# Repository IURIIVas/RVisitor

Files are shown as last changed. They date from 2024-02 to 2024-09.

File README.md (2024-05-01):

# RVisitor

Automated robot motion control module

## Description

The module allows to assign the control functions of a wheeled robot to a separate functional unit, reducing the requirements for robot software.   

### Application area
The module provides control of DC motors taking into account information from connected sensors. The module can be used for:
* studying the basic robotic algorithms for controlling the movement of wheeled robots
* research and development of robotic platforms

### Features

* setting and maintaining speed and direction of movement
* identification of obstacles and lack of surface
* wheel odometry
* high current level detection
* configuration save

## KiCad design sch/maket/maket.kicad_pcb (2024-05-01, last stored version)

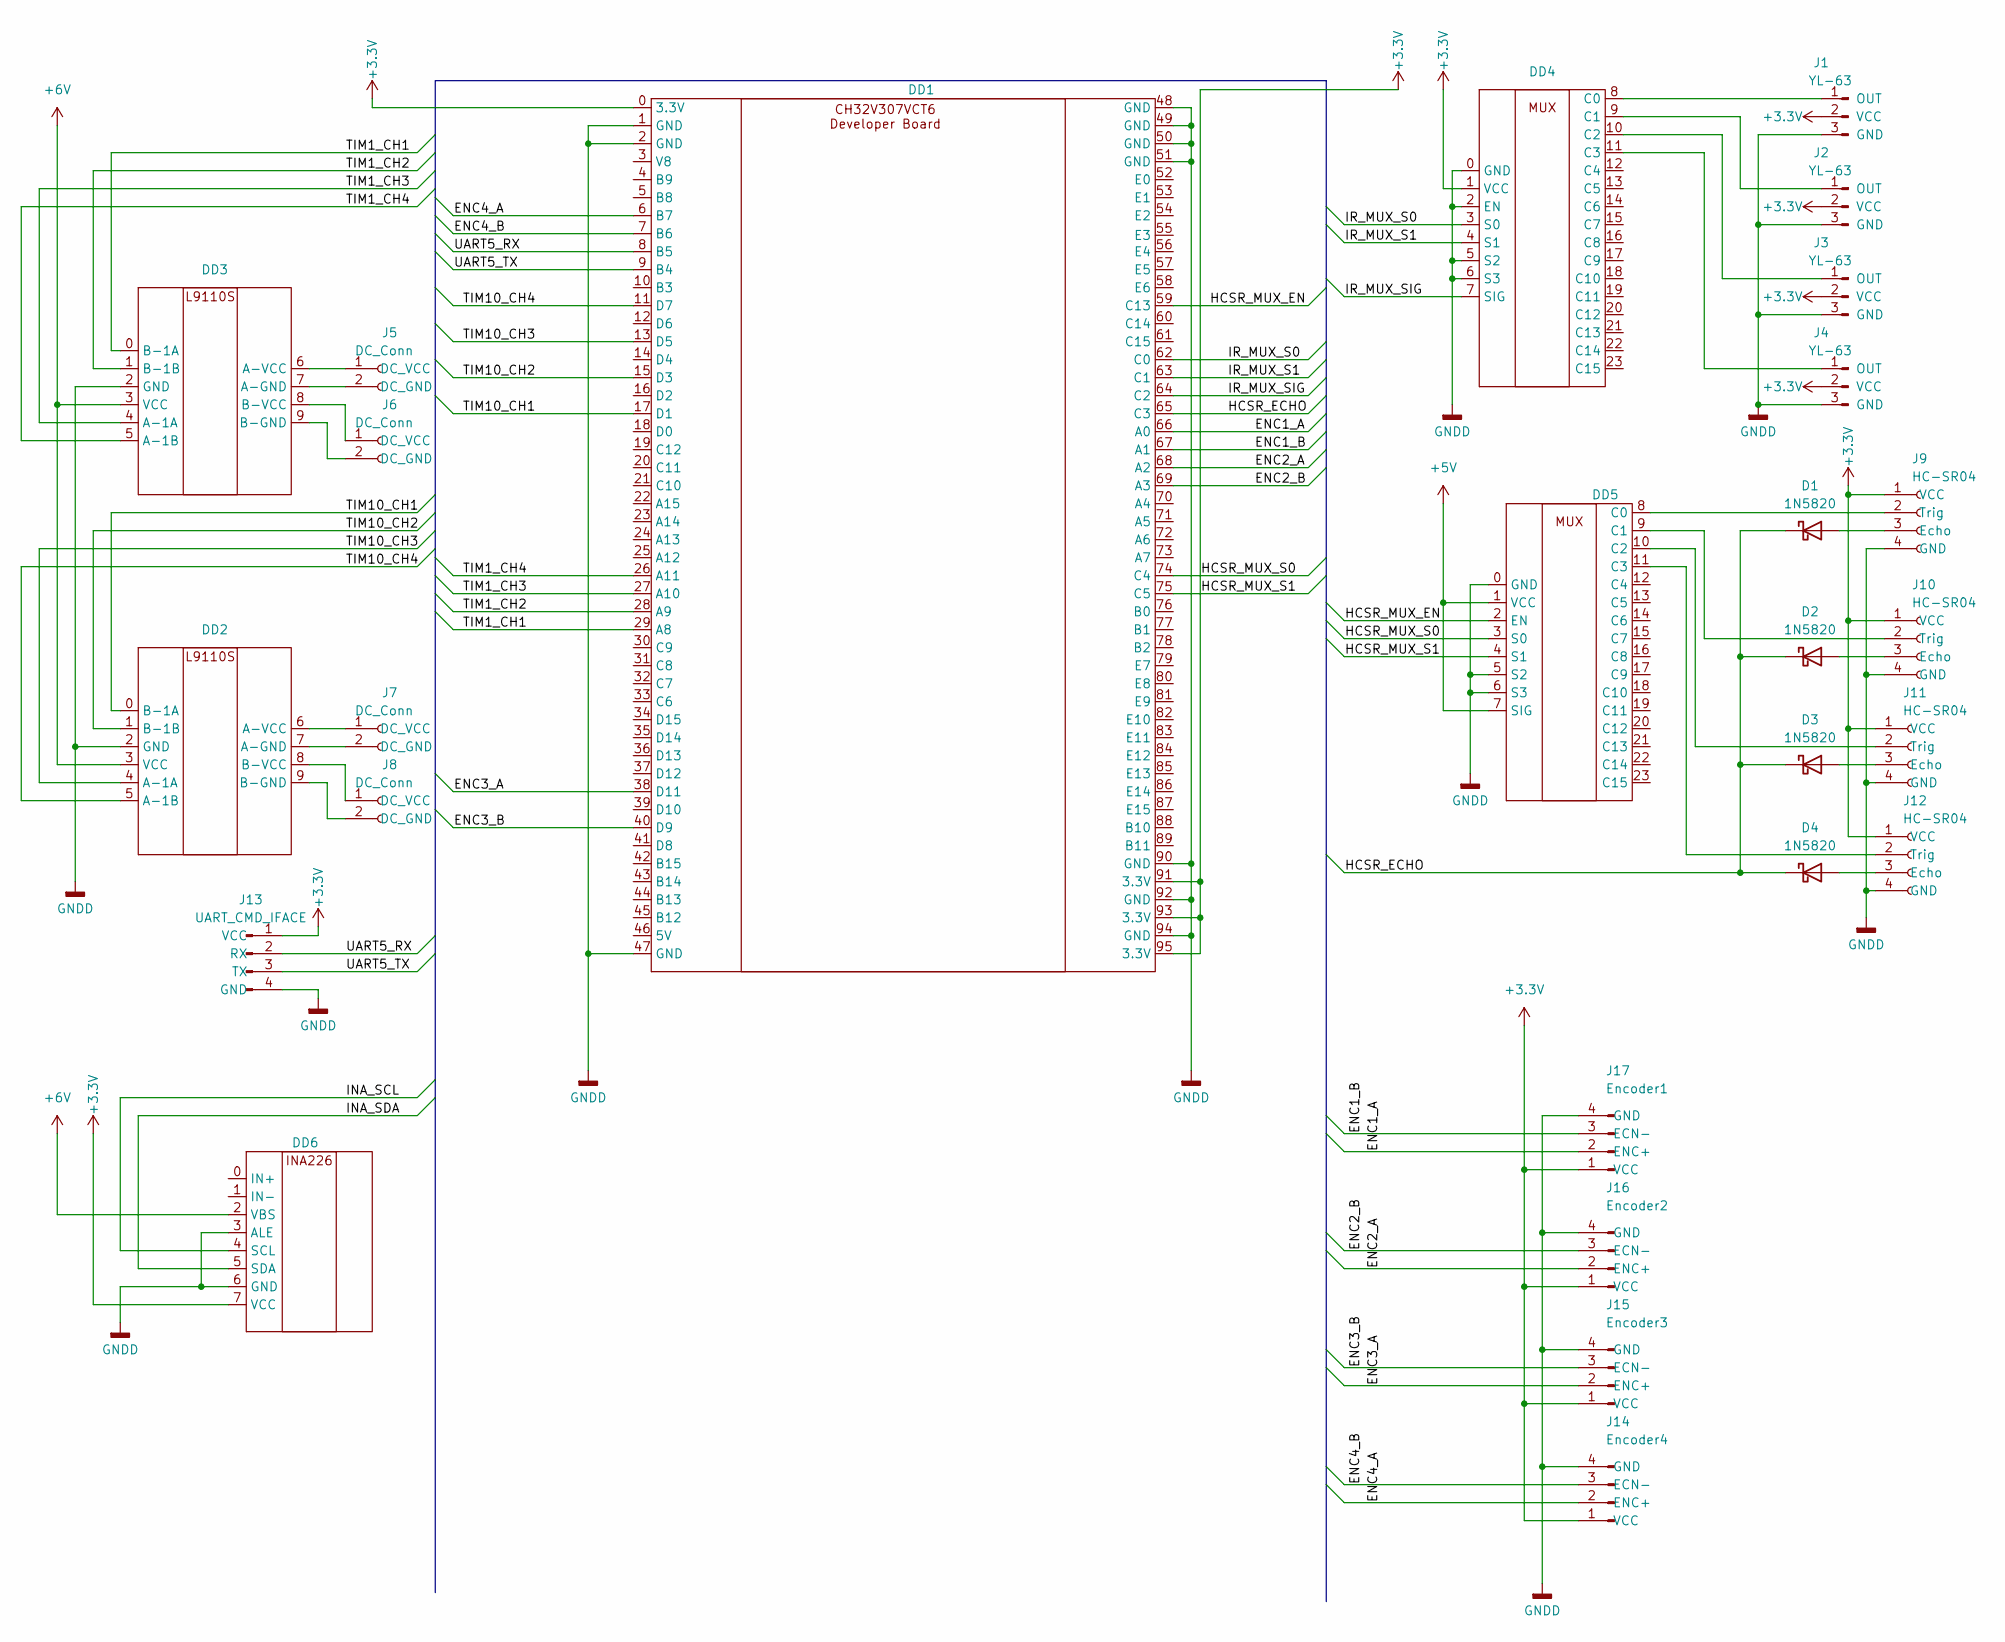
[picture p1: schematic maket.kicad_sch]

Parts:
D1, D2, D3, D4: 1N5820; D_DO-201AD_P15.24mm_Horizontal
DD1: CH32V307VCT6 dev board
DD2, DD3: L9110S
DD4, DD5: CD74HC4067_GOOD
DD6: INA226
J1, J2, J3, J4: YL-63; PinHeader_1x03_P2.54mm_Vertical
J5, J6, J7, J8: DC_Conn; JST_PH_S2B-PH-K_1x02_P2.00mm_Horizontal
J9, J10, J11, J12: HC-SR04; PinSocket_1x04_P2.54mm_Vertical
J13: UART_CMD_IFACE; PinSocket_1x04_P2.54mm_Vertical
J14: Encoder4; JST_PH_S4B-PH-K_1x04_P2.00mm_Horizontal
J15: Encoder3; JST_PH_S4B-PH-K_1x04_P2.00mm_Horizontal
J16: Encoder2; JST_PH_S4B-PH-K_1x04_P2.00mm_Horizontal
J17: Encoder1; JST_PH_S4B-PH-K_1x04_P2.00mm_Horizontal

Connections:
+3.3V: DD1.0 (3.3V), DD1.74 (C4), DD1.75 (C5), DD1.91 (3.3V), DD1.93 (3.3V), DD1.95 (3.3V), DD4.1 (VCC), DD5.3 (S0), DD5.4 (S1), DD6.7 (VCC), J1.2 (VCC), J2.2 (VCC), J3.2 (VCC), J4.2 (VCC), J9.1 (VCC), J10.1 (VCC), J11.1 (VCC), J12.1 (VCC), J13.1 (VCC), J14.1 (VCC), J15.1 (VCC), J16.1 (VCC), J17.1 (VCC)
+5V: DD5.1 (VCC), DD5.7 (SIG)
+6V: DD2.3 (VCC), DD3.3 (VCC), DD6.2 (VBS)
/ENC1_A: DD1.66 (A0), J17.2 (ENC+)
/ENC1_B: DD1.67 (A1), J17.3 (ECN-)
/ENC2_A: DD1.68 (A2), J16.2 (ENC+)
/ENC2_B: DD1.69 (A3), J16.3 (ECN-)
/ENC3_A: DD1.38 (D11), J15.2 (ENC+)
/ENC3_B: DD1.40 (D9), J15.3 (ECN-)
/ENC4_A: DD1.6 (B7), J14.2 (ENC+)
/ENC4_B: DD1.7 (B6), J14.3 (ECN-)
/HCSR_ECHO: D1.1 (K), D2.1 (K), D3.1 (K), D4.1 (K), DD1.65 (C3)
/HCSR_MUX_EN: DD1.59 (C13), DD5.2 (EN)
/INA_SCL: DD6.4 (SCL)
/INA_SDA: DD6.5 (SDA)
/IR_MUX_S0: DD1.62 (C0), DD4.3 (S0)
/IR_MUX_S1: DD1.63 (C1), DD4.4 (S1)
/IR_MUX_SIG: DD1.64 (C2), DD4.7 (SIG)
/TIM1_CH1: DD1.29 (A8), DD3.0 (B-1A)
/TIM1_CH2: DD1.28 (A9), DD3.1 (B-1B)
/TIM1_CH3: DD1.27 (A10), DD3.4 (A-1A)
/TIM1_CH4: DD1.26 (A11), DD3.5 (A-1B)
/TIM10_CH1: DD1.17 (D1), DD2.0 (B-1A)
/TIM10_CH2: DD1.15 (D3), DD2.1 (B-1B)
/TIM10_CH3: DD1.13 (D5), DD2.4 (A-1A)
/TIM10_CH4: DD1.11 (D7), DD2.5 (A-1B)
/UART5_RX: DD1.8 (B5), J13.2 (RX)
/UART5_TX: DD1.9 (B4), J13.3 (TX)
GNDD: DD1.1 (GND), DD1.2 (GND), DD1.47 (GND), DD1.48 (GND), DD1.49 (GND), DD1.50 (GND), DD1.51 (GND), DD1.90 (GND), DD1.92 (GND), DD1.94 (GND), DD2.2 (GND), DD3.2 (GND), DD4.0 (GND), DD4.2 (EN), DD4.5 (S2), DD4.6 (S3), DD5.0 (GND), DD5.5 (S2), DD5.6 (S3), DD6.3 (ALE), DD6.6 (GND), J1.3 (GND), J2.3 (GND), J3.3 (GND), J4.3 (GND), J9.4 (GND), J10.4 (GND), J11.4 (GND), J12.4 (GND), J13.4 (GND), J14.4 (GND), J15.4 (GND), J16.4 (GND), J17.4 (GND)
unnamed: D1.2 (A), J9.3 (Echo)
unnamed: D2.2 (A), J10.3 (Echo)
unnamed: D3.2 (A), J11.3 (Echo)
unnamed: D4.2 (A), J12.3 (Echo)
unnamed: DD2.7 (A-GND), J7.2 (DC_GND)
unnamed: DD2.6 (A-VCC), J7.1 (DC_VCC)
unnamed: DD2.9 (B-GND), J8.2 (DC_GND)
unnamed: DD2.8 (B-VCC), J8.1 (DC_VCC)
unnamed: DD3.7 (A-GND), J5.2 (DC_GND)
unnamed: DD3.6 (A-VCC), J5.1 (DC_VCC)
unnamed: DD3.9 (B-GND), J6.2 (DC_GND)
unnamed: DD3.8 (B-VCC), J6.1 (DC_VCC)
unnamed: DD4.8 (C0), J1.1 (OUT)
unnamed: DD4.9 (C1), J2.1 (OUT)
unnamed: DD4.10 (C2), J3.1 (OUT)
unnamed: DD4.11 (C3), J4.1 (OUT)
unnamed: DD5.8 (C0), J9.2 (Trig)
unnamed: DD5.9 (C1), J10.2 (Trig)
unnamed: DD5.10 (C2), J11.2 (Trig)
unnamed: DD5.11 (C3), J12.2 (Trig)

Board: 2 copper layers, 27 parts (0 on the bottom side), 47 nets, no tracks yet.

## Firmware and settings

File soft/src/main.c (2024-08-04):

/// \file main.c
/// \brief Main file.
/// \author 1jura.vas@gmail.com
///
/// \details
///

//----------------------------------------------------- Includes -------------------------------------------------------

#include "global_inc.h"
#include "misc.h"
#include "system_ch32v30x.h"

#ifndef G_TESTBENCH
	#include "motion_control.h"
    #include "cmd_interface.h"
#else
    #include "testbench.h"
#endif

//------------------------------------------------------ Macros --------------------------------------------------------

//----------------------------------------------------- Typedefs -------------------------------------------------------

//---------------------------------------------------- Variables -------------------------------------------------------

//------------------------------------------------ Function prototypes -------------------------------------------------

//------------------------------------------------- Inline Functions ---------------------------------------------------

//------------------------------------------------- Static Functions ---------------------------------------------------

//---------------------------------------------------- Functions -------------------------------------------------------

#ifndef G_TESTBENCH

void tasks_init(void)
{
    cmd_iface_listening_task_init();
    motion_control_task_init();
}

#endif

/// \brief Main Function
/// \param None
/// \return None
int main(void)
{

    nvic_priority_group_config(NVIC_PriorityGroup_2);
    SystemCoreClockUpdate();

#ifndef G_TESTBENCH
    tasks_init();

    vTaskStartScheduler();
#else
    testbench_init();
#endif

    while(1) {
	}
}

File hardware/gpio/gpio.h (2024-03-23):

/********************************** (C) COPYRIGHT  *******************************
* File Name          : ch32v30x_gpio.h
* Author             : WCH
* Version            : V1.0.0
* Date               : 2021/06/06
* Description        : This file contains all the functions prototypes for the 
*                      GPIO firmware library.
* Copyright (c) 2021 Nanjing Qinheng Microelectronics Co., Ltd.
* Attention: This software (modified or not) and binary are used for 
* microcontroller manufactured by Nanjing Qinheng Microelectronics.
*******************************************************************************/ 
#ifndef __CH32V30x_GPIO_H
#define __CH32V30x_GPIO_H

#ifdef __cplusplus
 extern "C" {
#endif

#include "ch32v30x.h"
                                 
/* Output Maximum frequency selection */
typedef enum
{ 
    GPIO_INPUT_MODE = 0,
    GPIO_SPEED_10MHZ = 1,
    GPIO_SPEED_2MHZ = 2,
    GPIO_SPEED_50MHZ = 3
} gpio_speed_e;

/* Configuration Mode enumeration */
typedef enum
{
    GPIO_MODE_AIN = 0x0,
    GPIO_MODE_IN_FLOATING = 0x04,
    GPIO_MODE_IPD = 0x28,
    GPIO_MODE_IPU = 0x48,
    GPIO_MODE_OUT_OD = 0x14,
    GPIO_MODE_OUT_PP = 0x10,
    GPIO_MODE_AF_OD = 0x1C,
    GPIO_MODE_AF_PP = 0x18
} gpio_mode_e;

/* GPIO Init structure definition */
typedef struct
{
    uint16_t gpio_pins;             /* Specifies the GPIO pins to be configured.
                                    This parameter can be any value of @ref GPIO_pins_define */
    gpio_speed_e gpio_speed;  /* Specifies the speed for the selected pins.
                                    This parameter can be a value of @ref gpio_speed_e */
    gpio_mode_e gpio_mode;    /* Specifies the operating mode for the selected pins.
                                    This parameter can be a value of @ref gpio_mode_e */
} gpio_init_s;

/* Bit_SET and Bit_RESET enumeration */
typedef enum
{
    BIT_RESET = 0,
    BIT_SET = 1
} bit_action_e;

#define GPIO_NUM                    (16)

/* GPIO_pins_define */
#define GPIO_PIN_0                  ((uint16_t)0x0001)  /* Pin 0 selected */
#define GPIO_PIN_1                  ((uint16_t)0x0002)  /* Pin 1 selected */
#define GPIO_PIN_2                  ((uint16_t)0x0004)  /* Pin 2 selected */
#define GPIO_PIN_3                  ((uint16_t)0x0008)  /* Pin 3 selected */
#define GPIO_PIN_4                  ((uint16_t)0x0010)  /* Pin 4 selected */
#define GPIO_PIN_5                  ((uint16_t)0x0020)  /* Pin 5 selected */
#define GPIO_PIN_6                  ((uint16_t)0x0040)  /* Pin 6 selected */
#define GPIO_PIN_7                  ((uint16_t)0x0080)  /* Pin 7 selected */
#define GPIO_PIN_8                  ((uint16_t)0x0100)  /* Pin 8 selected */
#define GPIO_PIN_9                  ((uint16_t)0x0200)  /* Pin 9 selected */
#define GPIO_PIN_10                 ((uint16_t)0x0400)  /* Pin 10 selected */
#define GPIO_PIN_11                 ((uint16_t)0x0800)  /* Pin 11 selected */
#define GPIO_PIN_12                 ((uint16_t)0x1000)  /* Pin 12 selected */
#define GPIO_PIN_13                 ((uint16_t)0x2000)  /* Pin 13 selected */
#define GPIO_PIN_14                 ((uint16_t)0x4000)  /* Pin 14 selected */
#define GPIO_PIN_15                 ((uint16_t)0x8000)  /* Pin 15 selected */
#define GPIO_PIN_ALL                ((uint16_t)0xFFFF)  /* All pins selected */
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

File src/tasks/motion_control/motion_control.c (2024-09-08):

/// \file dc_motor_controller.c
/// \brief set pwm connected to dc motors
/// \author 1jura.vas@gmail.com
///
/// \details
///

//----------------------------------------------------- Includes -------------------------------------------------------

#include "odometry.h"
#include "motion_control.h"
#include "dc_motor_controller.h"
#include "dc_motor_driver.h"
#include "encoder_driver.h"
#include "queue.h"
#include <math.h>

#include "cmd_interface.h"

//------------------------------------------------------ Macros --------------------------------------------------------

//----------------------------------------------------- Typedefs -------------------------------------------------------

//---------------------------------------------------- Variables -------------------------------------------------------

TaskHandle_t motion_control_task_handler;

//------------------------------------------------ Function prototypes -------------------------------------------------

//------------------------------------------------- Inline Functions ---------------------------------------------------

//------------------------------------------------- Static Functions ---------------------------------------------------

//---------------------------------------------------- Functions -------------------------------------------------------


void motion_control_task(void *pvParameters)
{
	double kp = 0.5;
	double ki = 0.1;
	double kd = 0;

	m_pid_s pid_0 = {.kp = kp, .ki = ki, .kd = kd, .input = 0, .last_input = 0,
				   .out_max = MOTOR_MAX_VALUE, .out_min = MOTOR_MIN_VALUE, .output = 0,
				   .output_sum = 0, .target = dc_m_ctrl.target_speed_rpm[LS]};
	m_pid_s pid_1 = {.kp = kp, .ki = ki, .kd = kd, .input = 0, .last_input = 0,
				   .out_max = MOTOR_MAX_VALUE, .out_min = MOTOR_MIN_VALUE, .output = 0,
				   .output_sum = 0, .target = dc_m_ctrl.target_speed_rpm[LS]};
	m_pid_s pid_2 = {.kp = kp, .ki = ki, .kd = kd, .input = 0, .last_input = 0,
				   .out_max = MOTOR_MAX_VALUE, .out_min = MOTOR_MIN_VALUE, .output = 0,
				   .output_sum = 0, .target = dc_m_ctrl.target_speed_rpm[RS]};
	m_pid_s pid_3 = {.kp = kp, .ki = ki, .kd = kd, .input = 0, .last_input = 0,
				   .out_max = MOTOR_MAX_VALUE, .out_min = MOTOR_MIN_VALUE, .output = 0,
				   .output_sum = 0, .target = dc_m_ctrl.target_speed_rpm[RS]};

//	uart_send_str(CMD_IFACE_UART, "ENC;PID_OUT;CTRL\n");
	while(1) {
		for (size_t enc = FL_ENC; enc < ENC_NUM; enc++) {
			dc_m_ctrl.dc_motor_speed_rpm[enc] = get_speed_rpm(enc);
		}

		dc_motors_speed_set(&dc_m_ctrl, &pid_0, &pid_1, &pid_2, &pid_3);

//		uart_send_int(CMD_IFACE_UART, (int32_t) dc_m_ctrl.dc_motor_speed_rpm[2]);
//		uart_send_str(CMD_IFACE_UART, ";");
//		uart_send_int(CMD_IFACE_UART, (int32_t) pid_2.output);
//		uart_send_str(CMD_IFACE_UART, ";");
//		uart_send_int(CMD_IFACE_UART, (int32_t) dc_m_ctrl.dc_motor_speed_pwm[2]);
//		uart_send_str(CMD_IFACE_UART, "\n");
		vTaskDelay(PID_PERIOD_MS / portTICK_PERIOD_MS);
	}
}

///// \brief DC motor controller task. PID controller and flags check
///// \param None
///// \return None
void motion_control_task_init(void)
{
    gpio_tim_dc_init();
    pwm_for_dc_init(0, 0, 0, 0);

    gpio_tim_enc_init();
    enc_init();

    xTaskCreate((TaskFunction_t )motion_control_task,
                (const char*    )"motion_control",
                (uint16_t       )DC_MOTOR_CONTROLLER_TASK_STK_SIZE,
                (void*          )NULL,
                (UBaseType_t    )DC_MOTOR_CONTROLLER_TASK_PRIORITY,
                (TaskHandle_t*  )&motion_control_task_handler);
}

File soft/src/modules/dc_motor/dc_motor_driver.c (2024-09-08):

/// \file dc_motor_driver.c
/// \brief DC_Motor driver source file
/// \author 1jura.vas@gmail.com
///
/// \details
///

//----------------------------------------------------- Includes -------------------------------------------------------

#include "dc_motor_driver.h"
#include "tim.h"

//------------------------------------------------------ Macros --------------------------------------------------------

//----------------------------------------------------- Typedefs -------------------------------------------------------

//---------------------------------------------------- Variables -------------------------------------------------------

//------------------------------------------------ Function prototypes -------------------------------------------------

//------------------------------------------------- Inline Functions ---------------------------------------------------

static inline void _dc_ls_backward_run(void)
{
    LS_PWM_TIM->CCER &= (uint16_t)(~DC0_TIM1_CH1_OUTPUT_ENABLE);
    LS_PWM_TIM->CCER |= (uint16_t)(DC0_TIM1_CH2_OUTPUT_ENABLE);
    LS_PWM_TIM->CCER &= (uint16_t)(~DC1_TIM1_CH4_OUTPUT_ENABLE);
    LS_PWM_TIM->CCER |= (uint16_t)(DC1_TIM1_CH3_OUTPUT_ENABLE);
}

static inline void _dc_rs_backward_run(void)
{
    RS_PWM_TIM->CCER &= (uint16_t)(~DC2_TIM10_CH2_OUTPUT_ENABLE);
    RS_PWM_TIM->CCER |= (uint16_t)(DC2_TIM10_CH1_OUTPUT_ENABLE);
    RS_PWM_TIM->CCER &= (uint16_t)(~DC3_TIM10_CH3_OUTPUT_ENABLE);
    RS_PWM_TIM->CCER |= (uint16_t)(DC3_TIM10_CH4_OUTPUT_ENABLE);
}

static inline void _dc_ls_forward_run(void)
{
    LS_PWM_TIM->CCER &= (uint16_t)(~DC0_TIM1_CH2_OUTPUT_ENABLE);
    LS_PWM_TIM->CCER |= (uint16_t)(DC0_TIM1_CH1_OUTPUT_ENABLE);
    LS_PWM_TIM->CCER &= (uint16_t)(~DC1_TIM1_CH3_OUTPUT_ENABLE);
    LS_PWM_TIM->CCER |= (uint16_t)(DC1_TIM1_CH4_OUTPUT_ENABLE);
}

static inline void _dc_rs_forward_run(void)
{
    RS_PWM_TIM->CCER &= (uint16_t)(~DC2_TIM10_CH1_OUTPUT_ENABLE);
    RS_PWM_TIM->CCER |= (uint16_t)(DC2_TIM10_CH2_OUTPUT_ENABLE);
    RS_PWM_TIM->CCER &= (uint16_t)(~DC3_TIM10_CH4_OUTPUT_ENABLE);
    RS_PWM_TIM->CCER |= (uint16_t)(DC3_TIM10_CH3_OUTPUT_ENABLE);
}

static inline void _dc_stop(void)
{
    LS_PWM_TIM->CCER &= (uint16_t)(~DC0_TIM1_CH1_OUTPUT_ENABLE);
    LS_PWM_TIM->CCER &= (uint16_t)(~DC0_TIM1_CH2_OUTPUT_ENABLE);
    LS_PWM_TIM->CCER &= (uint16_t)(~DC1_TIM1_CH3_OUTPUT_ENABLE);
    LS_PWM_TIM->CCER &= (uint16_t)(~DC1_TIM1_CH4_OUTPUT_ENABLE);
    RS_PWM_TIM->CCER &= (uint16_t)(~DC2_TIM10_CH1_OUTPUT_ENABLE);
    RS_PWM_TIM->CCER &= (uint16_t)(~DC2_TIM10_CH2_OUTPUT_ENABLE);
    RS_PWM_TIM->CCER &= (uint16_t)(~DC3_TIM10_CH3_OUTPUT_ENABLE);
    RS_PWM_TIM->CCER &= (uint16_t)(~DC3_TIM10_CH4_OUTPUT_ENABLE);
}

static inline void _dc_forward_run(void)
{
    _dc_ls_forward_run();
    _dc_rs_forward_run();
}

static inline void _dc_backward_run(void)
{
    _dc_ls_backward_run();
    _dc_rs_backward_run();
}

//------------------------------------------------- Static Functions ---------------------------------------------------


//---------------------------------------------------- Functions -------------------------------------------------------

void gpio_tim_dc_init(void)
{
    RCC_APB2PeriphClockCmd(RCC_APB2Periph_AFIO, ENABLE);
    AFIO->PCFR2 |= GPIO_FULLREMAP_TIM10;

    gpio_init_s gpio_left_side_init_struct = {0};

    gpio_left_side_init_struct.gpio_pins = GPIO_PIN_8 | GPIO_PIN_9
                                     | GPIO_PIN_10 | GPIO_PIN_11;
    gpio_left_side_init_struct.gpio_mode = GPIO_MODE_AF_PP;
    gpio_left_side_init_struct.gpio_speed = GPIO_SPEED_50MHZ;

    gpio_init_s gpio_right_side_init_struct = {0};

    gpio_right_side_init_struct.gpio_pins = GPIO_PIN_1 | GPIO_PIN_3
                                     | GPIO_PIN_5 | GPIO_PIN_7;
    gpio_right_side_init_struct.gpio_mode = GPIO_MODE_AF_PP;
    gpio_right_side_init_struct.gpio_speed = GPIO_SPEED_50MHZ;

    RCC_APB2PeriphClockCmd(RCC_APB2Periph_GPIOA, ENABLE);
    gpio_init(LS_GPIO, &gpio_left_side_init_struct);

    RCC_APB2PeriphClockCmd(RCC_APB2Periph_GPIOD, ENABLE);
    gpio_init(RS_GPIO, &gpio_right_side_init_struct);
}


/// \brief  Timer init for PWM mode
///         duty cycle = pulse/period
///         period - autoreload value
///         prescaler - f_pwm = f_apb2 / (psc + 1)
///         pulse - compare this value with period. If equal, change output.
/// \param
///         dc_0_speed - speed for dc0
///         dc_1_speed - speed for dc1
///         dc_2_speed - speed for dc2
///         dc_3_speed - speed for dc3
/// \return None
void pwm_for_dc_init(uint32_t dc_0_speed, uint32_t dc_1_speed,
                             uint32_t dc_2_speed, uint32_t dc_3_speed)
{
    RCC_APB2PeriphClockCmd(RCC_APB2Periph_TIM1, ENABLE);
    RCC_APB2PeriphClockCmd(RCC_APB2Periph_TIM10, ENABLE);

    uint32_t period = MOTOR_MAX_VALUE;
    uint32_t prescaler = MOTOR_PWM_PRESCALER - 1;

    tim_time_base_init_s tim_time_base_init_struct = {0};

    tim_time_base_init_struct.TIM_Period = period;
    tim_time_base_init_struct.TIM_Prescaler = prescaler;
    tim_time_base_init_struct.TIM_ClockDivision = TIM_CKD_DIV1;
    tim_time_base_init_struct.TIM_CounterMode = TIM_CounterMode_Up;

    tim_oc_init_t tim_dc_oc_init_struct = {0};

    tim_dc_oc_init_struct.TIM_OCMode = PWM_MODE;
    tim_dc_oc_init_struct.TIM_OutputState = TIM_OutputState_Enable;
    tim_dc_oc_init_struct.TIM_OCPolarity = TIM_OCPolarity_Low;

    TIM_TimeBaseInit(LS_PWM_TIM, &tim_time_base_init_struct);
    TIM_TimeBaseInit(RS_PWM_TIM, &tim_time_base_init_struct);

    tim_dc_oc_init_struct.TIM_Pulse = dc_0_speed;
    TIM_OC1Init(LS_PWM_TIM, &tim_dc_oc_init_struct);
    TIM_OC2Init(LS_PWM_TIM, &tim_dc_oc_init_struct);

    tim_dc_oc_init_struct.TIM_Pulse = dc_1_speed;
    TIM_OC3Init(LS_PWM_TIM, &tim_dc_oc_init_struct);
    TIM_OC4Init(LS_PWM_TIM, &tim_dc_oc_init_struct);

    tim_dc_oc_init_struct.TIM_Pulse = dc_2_speed;
    TIM_OC1Init(RS_PWM_TIM, &tim_dc_oc_init_struct);
    TIM_OC2Init(RS_PWM_TIM, &tim_dc_oc_init_struct);

    tim_dc_oc_init_struct.TIM_Pulse = dc_3_speed;
    TIM_OC3Init(RS_PWM_TIM, &tim_dc_oc_init_struct);
    TIM_OC4Init(RS_PWM_TIM, &tim_dc_oc_init_struct);

    _dc_stop();

    TIM_CtrlPWMOutputs(LS_PWM_TIM, ENABLE);
    TIM_CtrlPWMOutputs(RS_PWM_TIM, ENABLE);

    TIM_OC1PreloadConfig(LS_PWM_TIM, TIM_OCPreload_Enable);
    TIM_OC2PreloadConfig(LS_PWM_TIM, TIM_OCPreload_Enable);
    TIM_OC3PreloadConfig(LS_PWM_TIM, TIM_OCPreload_Enable);
    TIM_OC4PreloadConfig(LS_PWM_TIM, TIM_OCPreload_Enable);
    TIM_OC1PreloadConfig(RS_PWM_TIM, TIM_OCPreload_Enable);
    TIM_OC2PreloadConfig(RS_PWM_TIM, TIM_OCPreload_Enable);
    TIM_OC3PreloadConfig(RS_PWM_TIM, TIM_OCPreload_Enable);
    TIM_OC4PreloadConfig(RS_PWM_TIM, TIM_OCPreload_Enable);

    TIM_ARRPreloadConfig(LS_PWM_TIM, DISABLE);
    TIM_ARRPreloadConfig(RS_PWM_TIM, DISABLE);

    TIM_Cmd(LS_PWM_TIM, ENABLE);
    TIM_Cmd(RS_PWM_TIM, ENABLE);
}
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

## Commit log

2023-10-18 Initial commit. Blink LEDs Function
2023-10-21 Command Interface on USART2. print Hello World and unknown command added to command interface.
2023-10-22 IR sensor HW-201 init.
2023-11-09 dc motor 0 driver. change direction with cmd interface
2023-11-26 Change USART2 pins to GPIOD. GPIO init function of hw-201 fixed
    [cmd_interface.c, hw_201_survey.c]
2023-11-28 HC_SR04 capture started. Added Trig pin functionality with timer and gpio.
2023-11-30 trig pin enable function fixed, 9 timer used to count 10 microseconds
    [hc_sr04_survey.c]
2023-12-11 pid controller develop started.
    - change vTaskDelay from ticks to ms
    - delete blink_led_task
    - convert string to double function added
    - pow function added
2023-12-13 cmd interface sends data in 2 seconds dc_control only by pid, in cmd iface only speed requiered all settings goes to struct tim8 changed to tim10 tim3 changed to tim9 usart2 changed to uart5 defined 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
2023-12-17 function string to double changed tim for dc control changed, from tim8 to tim10 tim3 changes for tim9 hc_sr04 now not working, because of no timer
    [cmd_interface.c, dc_motor_driver.c, dc_motor_driver.h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]
2023-12-17 working pid
2023-12-17 odometry task. calculate odometry with encoder values dc_motor name added uart_send_double function added
2023-12-17 spi flash init
2023-12-21 spi flash driver init
2023-12-24 ina226 i2c lib
2023-12-24 ina226 get current and voltage task
2023-12-25 get current and voltage cmd in command interface
2023-12-26 fixed timer on hc_sr04
    [cmd_interface.c, hc_sr04_survey.c]
2024-01-05 dc_motor_driver fixed. brief on hc_sr04_added. i2c wrong tranciever fixed. flags active param added
    [cmd_interface.c, dc_motor_controller.c, dc_motor_controller.h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]
2024-01-05 testbench configuration. spi flash test
2024-01-10 [debug][motor_controller] => dc_motor_driver task deleted. converted to module and relocated to dc_motor_controller task => odometry task deleted. converted to module and relocated to dc_motor_contro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
2024-01-10 [debug][cmd_interface] => check if written parameters to flash is correct
    [cmd_interface.c]
2024-01-10 [rework] => project structure changed => all soft moved to ./soft folder => doc folder for doxygen generation added => sch folder for schematic added
    [maket.kicad_pcb, maket.kicad_sch]
2024-01-10 [odometry][cmd_iface] => corrected print double function. fixed skipped 0 after dot and double - => odometry threshold added. if left side and right side differs less than 0.001 meter than left_side 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
    [dc_motor_controller.c, odometry.c, uart.c]
2024-02-22 [sch] new board add
    [dc_motor.kicad_sch, mcu.kicad_sch, power.kicad_sch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]
2024-03-23 [sch] rvisitor_module_board_v1 => power lines added
    [dc_motor.kicad_sch, power.kicad_sch, sensors.kicad_sch]
2024-03-23 [soft] rework => Start reworking vendors lib => GPIO lib reworked => core_riscv reworked
    [cmd_interface.c, dc_motor_controller.c, dc_motor_driver.c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]
2024-04-25 maket pcb start. maket add footprints. module_board_v1 start
    [dc_motor.kicad_sch, maket.kicad_pcb, maket.kicad_sch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]
2024-05-01 PCB module. readme update
    [maket.kicad_pcb, maket.kicad_sch]
2024-08-04 dc motor controller with pid working mode
2024-09-08 encoders and dc motor map new maket board implemented
2024-11-13 Removed project dirs
    [dc_motor.kicad_sch, maket.kicad_pcb, maket.kicad_sch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]
